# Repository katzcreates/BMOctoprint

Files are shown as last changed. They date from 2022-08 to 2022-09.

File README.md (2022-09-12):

# BMOctoprint: The DIY Octoprint Server Shaped like BMO from Adventure Time!

So you followed along with my [BMOctoprint](https://katzcreates.com/portfolio/bmoctoprint) project and want to try your hand at making your own? Well, congratulations! You're in the right place and you are in for a treat because BMOctoprint is the sweetest, cutest, loveliest Octoprint server there ever was. 

All of the files you need to recreate my version of BMOctoprint can be found here in this repository. However, if you wish to make alterations to make BMO your own, you are encouraged to do so! You can even create forks of this repository to add your own code or altered 3D printing files. I would love to see what other versions of BMO people can make with what I have started, so please share your results if you end out taking a different approach!

### The full, detailed build instructions can be found on [here on Instructables](https://www.instructables.com/Life-Sized-Talking-BMO-From-Adventure-Time-thats-A/).

## Getting Started

This is a rather involved build with a fair bit of expenditure involved with a handful of parts being needed! Below are the components/necessary materials that I used to create BMOctoprint and therefore will work perfectly with the case/code as provided. If you wish to use different components then feel free, but alterations may be necessary to make everything fit!

### Electronics (links are not affiliate links and UK specific)
- A Raspberry Pi 4 (I used a 8GB model which worked great and I recommend it. A smaller model may be fine as well or may run a bit slower.)
   - (If you are going to be running Octoprint then a Pi 4 is a requirement as older models struggle to run it and I have not tested this setup with a Pi Zero.)
- [7 inch Raspberry Pi Touchscreen](https://shop.pimoroni.com/products/raspberry-pi-7-touchscreen-display-with-frame?variant=2677960835082)
   - (This is super easy to use, fits the case perfectly and allows the Pi to mount right to the back of it. It is also quite expensive and there are probably cheaper options that can work with adjustments.)
- [Adafruit I2S Speaker Bonnet](https://shop.pimoroni.com/products/adafruit-i2s-3w-stereo-speaker-bonnet-for-raspberry-pi-mini-kit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)
- One (1) extra long 40 pin header
- Two (2) [3 inch Speakers](https://shop.pimoroni.com/products/3-speaker-4-3w?variant=380549926)
- Three (3) [12mm Tactile Switches](https://shop.pimoroni.com/products/tactile-switches?variant=372242669)
- Four (4) [6mm Tactile Switches](https://shop.pimoroni.com/products/tactile-switches?variant=372242667)
- One (1) USB-C Panel Mount (capable of power delivery, this is important!!)
- Four (4) [USB-A Panel Mounts (2 Left Angle and 2 Right Angle)](https://www.ebay.co.uk/itm/232860372185)
- Seven (7) 10K resistors
- A custom [BMOctoprint PCB](https://www.pcbway.com/project/shareproject/BMOctoprint_Buttons_PCB_2d7beb47.html) or other mounting for the tactile switches

### Additional Components/Materials
- One (1) KG of [Teal PETG filament](https://eu.polymaker.com/product/polylite-petg/?aff=44) (affiliate link)
   - (Total printed weight will depend on your print settings, but 1KG should see you through)
- 50g Black PETG filament
- Small amounts of Yellow, Red, Green and Blue PLA
- 3mm Flexible Armature Wire
- Eight (8) M4x6 screws (cap head preferred for all screws)
- Four (4) M3x4 screws
- Eight (8) M3x8 screws
- Eight (8) M3x16 screws
- Two (2) 8x3mm Neodymium Magnets (optional)

I highly recommend a keyboard you can connect to the Pi as well to make setting things up easier, however, it is not required. You can do everything on the touchscreen, but it may take a lot longer than with a keyboard!

You will also require some basic electronics kit and tools such as a soldering iron, solder, a breadboard, kapton tape and a range of wiring. A 3D printer is essential as well, of course!
<br/>

### Pi Software Setup

To run all of the current code and software for BMOctoprint, you will need to use the **Buster OS** build of Raspbian. 
> The current build (Bullseye) will not work as OMXPlayer is not compatible with it. 

I recommend downloading and using the [Raspberry Pi Installer tool](https://www.raspberrypi.com/software/) to get this set up. 

#### Required Installs
- OMXPlayer ([Documentation](https://github.com/popcornmix/omxplayer))
- [OMXPlayer-Wrapper](https://pypi.org/project/omxplayer-wrapper/) ([Documentation](https://python-omxplayer-wrapper.readthedocs.io/en/latest/#))
- [Xscreensaver](https://www.jwz.org/xscreensaver/) ([Documentation](https://linux.die.net/man/1/xscreensaver-command))
- [Feh](https://feh.finalrewind.org/) ([Documentation](https://man.finalrewind.org/1/feh/))
- [Octoprint](https://octoprint.org/) (NOT Octopi!) ([Install Instructions](https://community.octoprint.org/t/setting-up-octoprint-on-a-raspberry-pi-running-raspberry-pi-os-debian/2337))

### Additional relevant instructions can be found inside the individual folders, and full detailed build instructions are on [here on Instructables](https://www.instructables.com/Life-Sized-Talking-BMO-From-Adventure-Time-thats-A/). If I missed anything or you get stuck, please open an issue or send a message and I'll be happy to try and help!
<br/>
<br/>
<br/>
<br/>

Shield: [][cc-by-nc-sa]

This work is licensed under a
[Creative Commons Attribution-NonCommercial-ShareAlike 4.0 International License][cc-by-nc-sa].

[][cc-by-nc-sa]

[cc-by-nc-sa]: http://creativecommons.org/licenses/by-nc-sa/4.0/
[cc-by-nc-sa-image]: https://licensebuttons.net/l/by-nc-sa/4.0/88x31.png
[cc-by-nc-sa-shield]: https://img.shields.io/badge/License-CC%20BY--NC--SA%204.0-lightgrey.svg

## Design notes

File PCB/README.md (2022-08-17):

PCB Gerber files can be found here! If you wish to manufacture the PCB yourself, please help yourself to the following files. 

I'd love to see other versions of this, so please share the results here or on social media if possible!

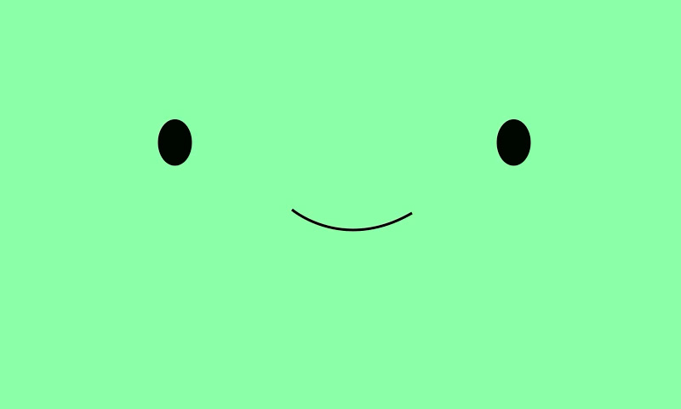
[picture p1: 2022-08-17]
Animation Files/BMO_Idle.jpg

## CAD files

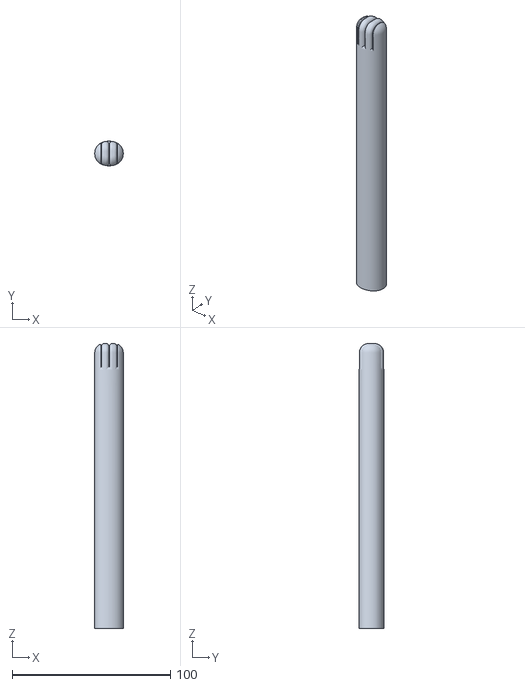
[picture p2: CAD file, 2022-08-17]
Print Files/BMOctoprint_Arm_Whole.stl
18.0 x 15.6 x 180.0

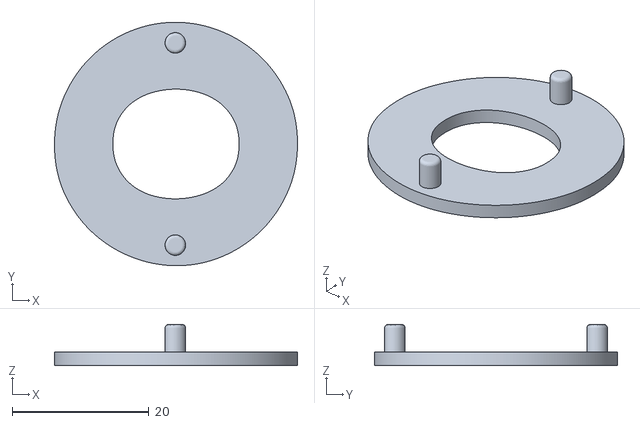
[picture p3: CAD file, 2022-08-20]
Print Files/BMOctoprint_O_Left.stl
35.5 x 35.5 x 6.00

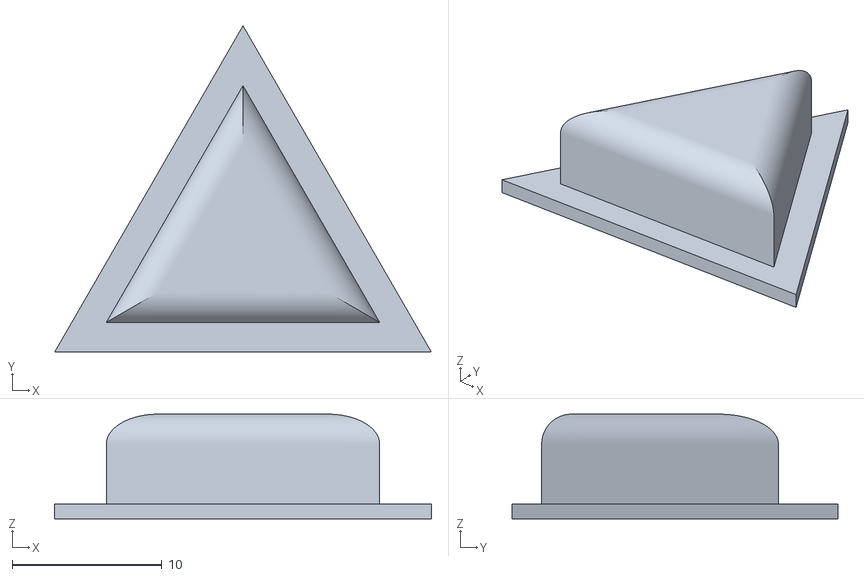
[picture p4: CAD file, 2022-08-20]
Print Files/BMOctoprint_BlueTriangleButton.stl
25.2 x 21.8 x 7.00

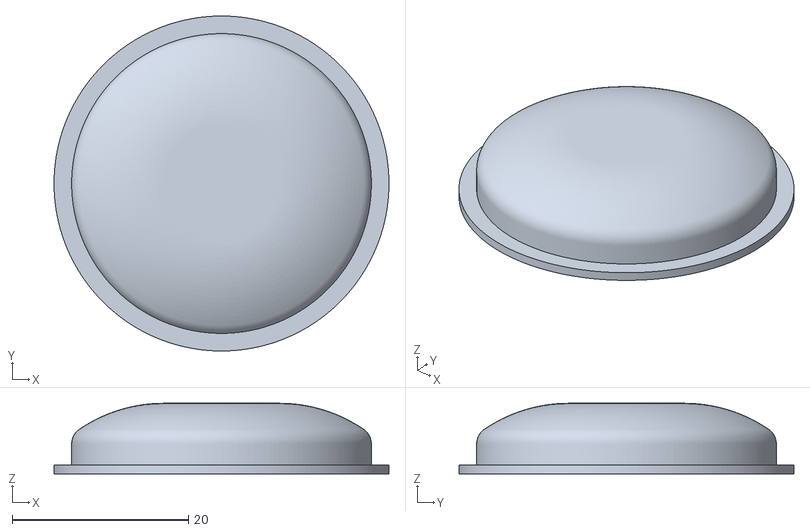
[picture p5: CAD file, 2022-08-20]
Print Files/BMOctoprint_BigRedButton.stl
38.0 x 38.0 x 8.00

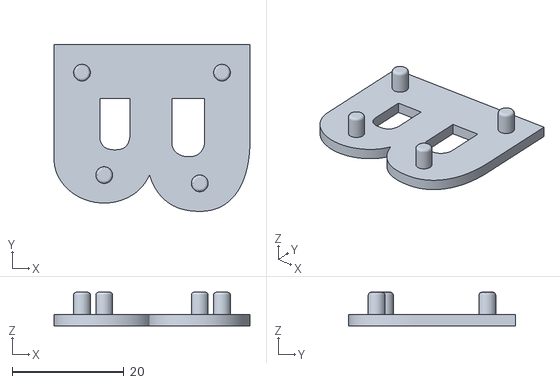
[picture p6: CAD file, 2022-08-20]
Print Files/BMOctoprint_B_Left.stl
35.0 x 29.8 x 6.00

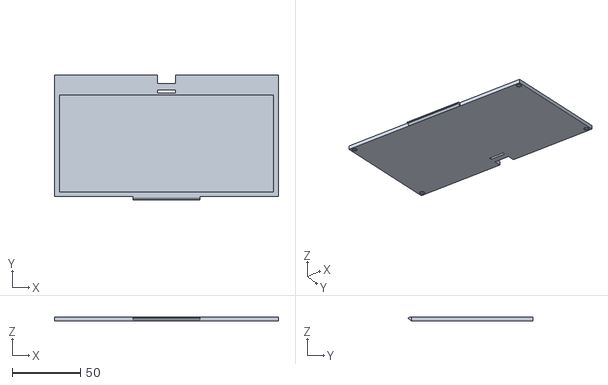
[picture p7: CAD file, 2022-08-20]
Print Files/BMOctoprint_ButtFlap.stl
164.0 x 91.3 x 3.00

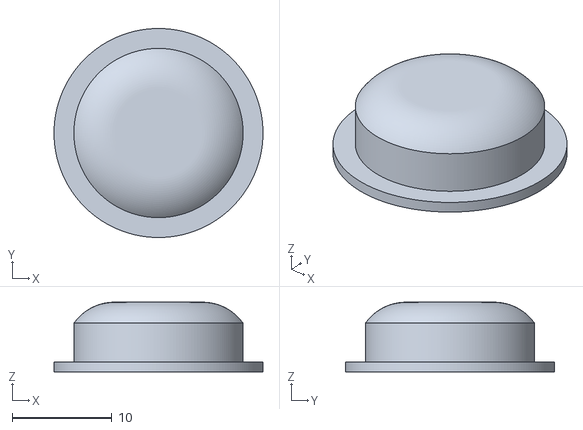
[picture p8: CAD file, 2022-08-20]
Print Files/BMOctoprint_SmallGreenButton.stl
21.0 x 21.0 x 7.00

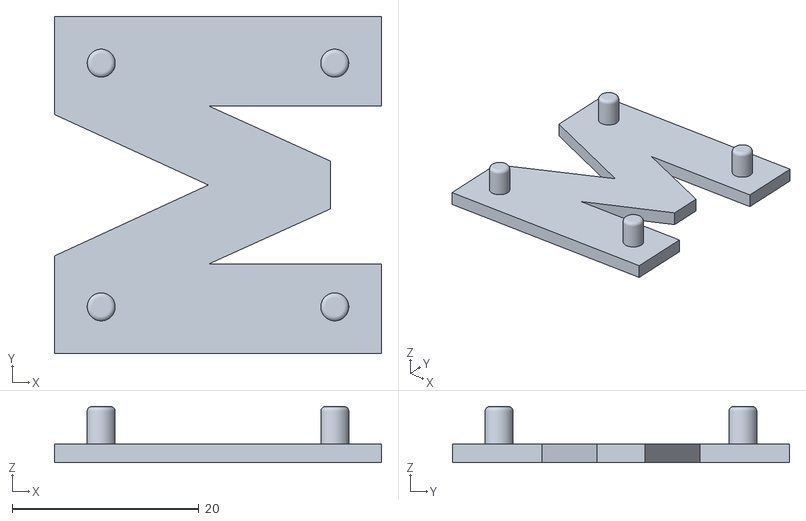
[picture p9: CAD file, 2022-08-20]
Print Files/BMOctoprint_M_Left.stl
35.0 x 36.1 x 6.00

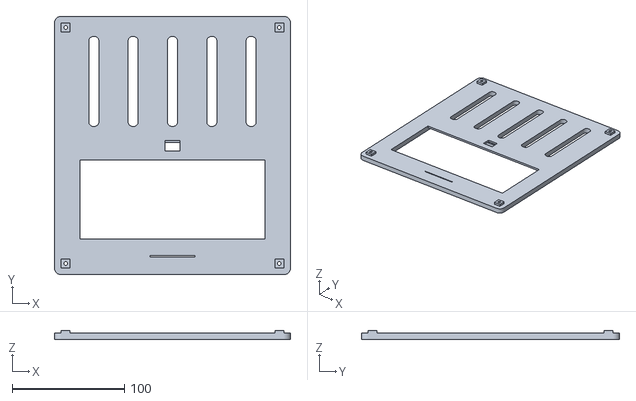
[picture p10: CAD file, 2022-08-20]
Print Files/BMOctoprint_BackPlate.stl
210.0 x 230.0 x 8.20

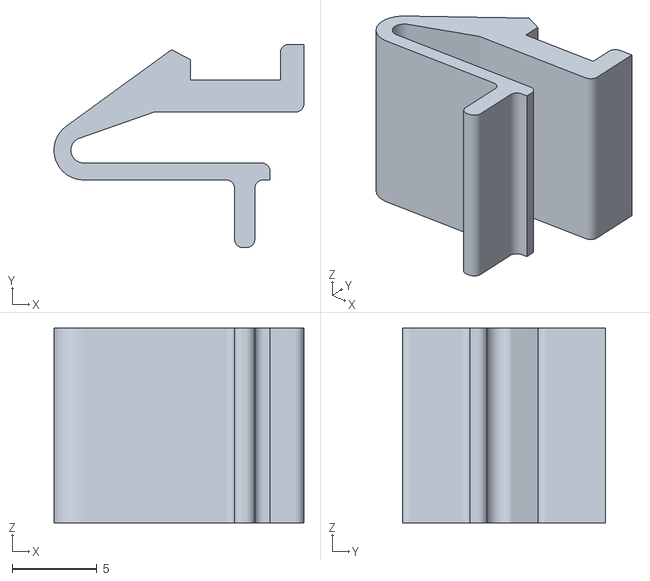
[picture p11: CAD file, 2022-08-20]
Print Files/BMOctoprint_ButtLatch.stl
14.7 x 12.0 x 11.5

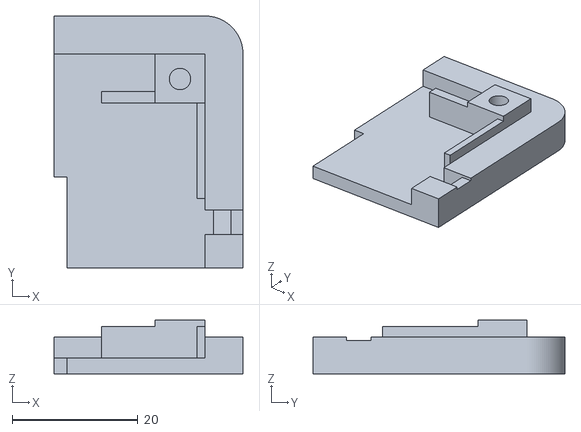
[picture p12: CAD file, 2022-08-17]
Print Files/TestFit_Front.stl
30.0 x 40.0 x 8.50

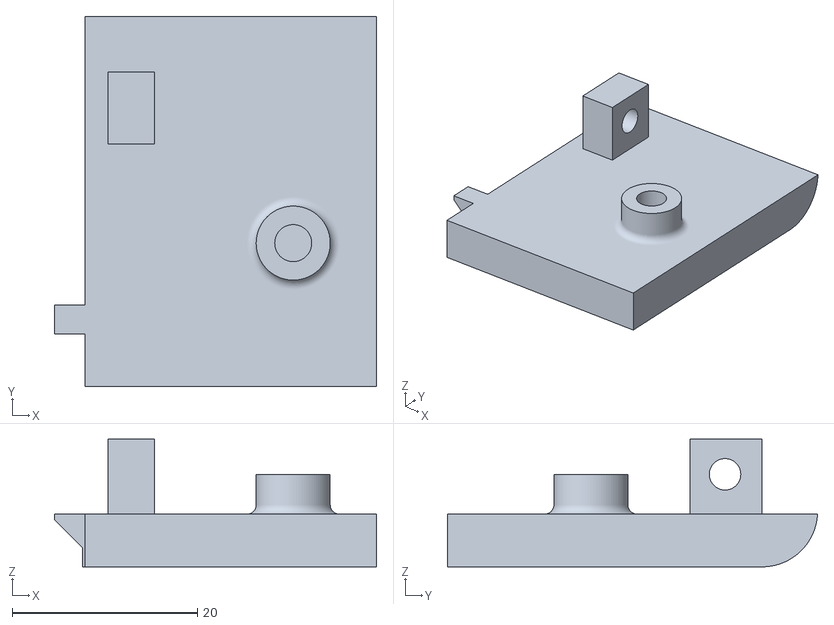
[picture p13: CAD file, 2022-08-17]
Print Files/TestFit_Right.stl
34.8 x 40.0 x 13.8

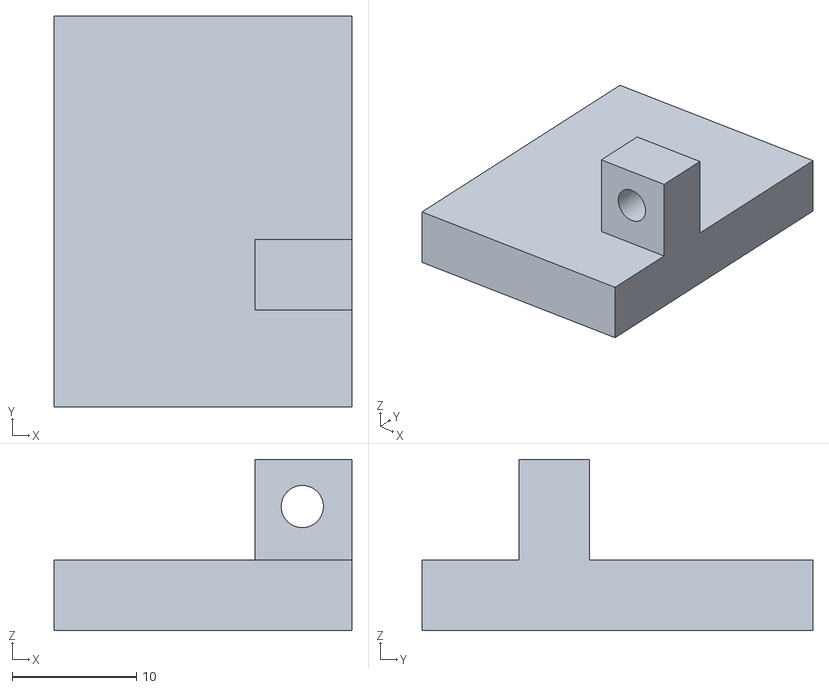
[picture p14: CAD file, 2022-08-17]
Print Files/TestFit_Top.stl
24.0 x 31.5 x 13.8

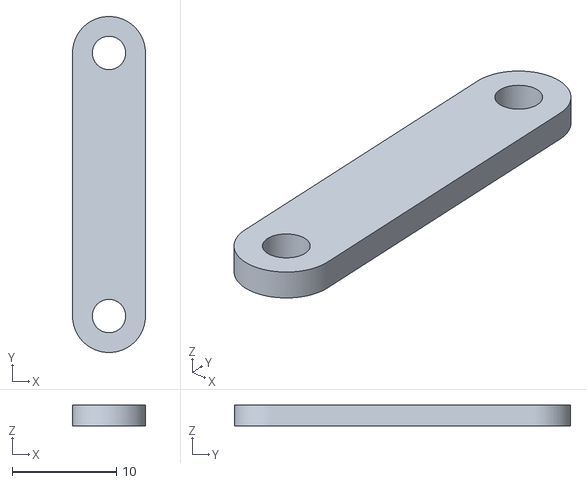
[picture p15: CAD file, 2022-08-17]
Print Files/BMOctoprint_DisplayMount01.stl
7.00 x 32.2 x 2.00

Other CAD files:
Print Files/BMOctoprint_DisplayMount02.stl
Print Files/BMOctoprint_LegPlug.stl
Print Files/BMOctoprint_FacePlate.stl
Print Files/BMOctoprint_LeftPlate.stl
Print Files/BMOctoprint.f3d
Print Files/BMOctoprint_ArmPlug.stl
Print Files/BMOctoprint_Arm_Segmented.stl
Print Files/BMOctoprint_B_Right.stl
Print Files/BMOctoprint_BottomPlate.stl
Print Files/BMOctoprint_DPad.stl
Print Files/BMOctoprint_DPad_ButtonPushPad.stl
Print Files/BMOctoprint_DPad_CenterPin.stl
Print Files/BMOctoprint_Faceplate_MiddleHoleCover.stl
Print Files/BMOctoprint_Faceplate_RoundHoleCover.stl
Print Files/BMOctoprint_Faceplate_SmallHoleCover.stl
Print Files/BMOctoprint_Hand_Segmented.stl
Print Files/BMOctoprint_LeftLeg.stl
Print Files/BMOctoprint_LegJoint.stl
Print Files/BMOctoprint_M_Right.stl
Print Files/BMOctoprint_O_Right.stl
Print Files/BMOctoprint_RightPlate.stl
Print Files/BMOctoprint_TopPlate.stl

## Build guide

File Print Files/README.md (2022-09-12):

# BMOctoprint 3D Printing Instructions

BMOctoprint's 3D printing files have been optimised to make printing as simple and straight forward as possible, **however**, as with all large 3D printing projects there is still a certain degree of prior 3D printing knowledge required to successfully create your build. 

## These are large prints! Please proceed with appropriate caution or risk wasting filament!

This folder contains all the individual pieces as **STL files**, as well as **CAD files** (.f3d and .STEP) that contain the whole model in 'assembled' form. The large case parts have been optimised for use with either a 0.4mm or 0.6mm nozzle, while the smaller pieces print best with either 0.4mm or smaller nozzles (I have successfully printed the buttons with a 0.1mm nozzle, but that is hardly necessary!). 

### I highly recommend printing the large case pieces with a 0.6mm nozzle to save on print time. While a 0.4mm nozzle can be used, it will take substantially more time and will not save on filament.

Tolerances should be fine for most printers, but it is still recommended that you print the provided **TestFit** pieces to check the fit of the pieces before committing to the larger prints. This will allow you to check the piece alignment/fit, as well as the fit for the screws. A M4x6 can be used to check the larger screw hole, and a M3x16 for the three aligned holes.

### **If you are struggling with tolerances and fit, it is possible to adjust these within the CAD files, but I'm afraid I cannot provide a range of part sizes for this due to the work involved. I am happy to advise on how to improve the fit but cannot provide additional files.** 

All STL files are in the best orientation for printing as is and don't require moving. Most pieces can be printed without supports, but minimal supports are required for some pieces. If unsure, print with supports!

Main case pieces and mounting pieces should be printed in PETG to handle the heat from the electronics without issue. I can highly recommend [Polymaker PolyLite PETG](https://eu.polymaker.com/product/polylite-petg/?aff=44) (affiliate link) in Teal for this, as it is the perfect BMO colour! 

BMO's limbs ideally should be printed in a soft TPU to allow for flexibility and posing! I used [Recreus Filaflex 82A in Blue](https://recreus.com/gb/filaments/9-694-filaflex-82a.html#/2-diameter-175_mm/3-weight-500_gr/14-colour-blue) with great results, [Polymaker PolyFlex 90A](https://eu.polymaker.com/product/polyflex-tpu90/?aff=44) (affiliate link) works as well if you struggle with softer TPU. The Arm model comes in two variations; a whole version and a segmented version. If you are struggling to print the whole version in one go but don't want to use the segmented version (less clean looking) it's also possible to 'slice' it into two pieces in your slicer of choice and use [TPU welding to put the two pieces together](https://www.instagram.com/reel/CcI-6JzDguU/?utm_source=ig_web_copy_link). **There are slots in the hands for neodymium magnets that can be pushed into place while the print is paused if you so desire.**

Buttons and other detail pieces can be printed in PLA or whatever you please! 

Some minor clean up may be required to get everything looking good and fitting together properly, but it should be minimal! If at all possible, print on a smooth or shiny print bed to get a BMO with a shiny surface! 

### Full build instructions can be found [here](https://www.instructables.com/Life-Sized-Talking-BMO-From-Adventure-Time-thats-A/).

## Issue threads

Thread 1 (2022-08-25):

while loop in python script causing high CPU consumption?

MatthewJohn, 2022-08-25:
I've just seen your video and looked at your python script..
I'm not sure if I'm missing something (in particular about how gpiozero.Button works)..
Looking at the documentation and how you're using gpiozero.Button, I think either of one these is true, which may cause unnecessary CPU usage:
 * Looping and checking each of the buttons - I imagine this is causing a high amount of CPU load? If octoprint is running in the background, maybe this could cause some print issues - perhaps a very small sleep at end of the for while loop would work (https://github.com/katzcreates/BMOctoprint/blob/main/Code%20Files/BMOFaceButtons.py#L68)?
```
    from time import sleep
    while True:
        button_right.when_pressed = video_right
        button_up.when_pressed = video_up
        button_down.when_pressed = video_down
        button_left.when_pressed = video_left
        sleep(0.1)

    pause()
```
 * Alternatively (and if true, a more beneficial change), having had a brief look at the docs/example for gpiozero.Button:
```
    from gpiozero import LED, Button:
    from signal import pause

    led = LED(17)
    button = Button(3)

    button.when_pressed = led.on
    button.when_released = led.off

    pause()
```
   the example appears to suggest that button.when_pressed is just setting up a callback for when the button is pressed. Therefore, once entering the thread `pause()`, the callback will happen, meaning the `while` loop is not necessary at all re-setting up the callback over and over, wasting CPU time. So it could look like:
```
    button_right.when_pressed = video_right
    button_up.when_pressed = video_up
    button_down.when_pressed = video_down
    button_left.when_pressed = video_left

    pause()
```

Apologies if I've missed something (either obvious or not) and I have absolutely no means of testing any of this (PI, 3d printer or BMO) :D

katzcreates, 2022-09-08:
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

Hey! Thank you so much for noting this. You are absolutely right; the `while` loop is not necessary and I had just missed that in the documentation. I've tested your theory and it is working perfectly! I shall update the code here so everyone can benefit from your insight. 😀 Thank you so much!

MatthewJohn, 2022-12-11:
For reference: aa8eac3b318e5cdad17138410bee72f418423924

Closed 2022-09-08.

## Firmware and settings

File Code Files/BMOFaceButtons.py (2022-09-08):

from gpiozero import Button #Much easier way to interact with the GPIO
from omxplayer import OMXPlayer
from pathlib import Path
import time
from signal import pause
import os
import subprocess

button_right = Button(6) 
button_up = Button(16)
button_left = Button (5)
button_down = Button (25)

def video_right():
    image = subprocess.Popen(["feh", "--hide-pointer", "-x", "-F", "/home/pi/BMO/BMO_Idle.jpg"])
    time.sleep(0.1)
    os.system("xscreensaver-command -deactivate")
    time.sleep(0.1)
    VIDEO_PATH = Path("/home/pi/BMO/BMO_DontSayThings_ColorAdjust.mp4")
    player = OMXPlayer(VIDEO_PATH, args=['-o', 'alsa'])
    player.set_aspect_mode('stretch')
    player.set_rate(0.975)
    time.sleep(4.7)
    os.system("xscreensaver-command -activate")
    image.kill()
    
    
def video_up():
    image = subprocess.Popen(["feh", "--hide-pointer", "-x", "-F", "/home/pi/BMO/BMO_Idle.jpg"])
    time.sleep(0.1)
    os.system("xscreensaver-command -deactivate")
    time.sleep(0.1)
    VIDEO_PATH = Path("/home/pi/BMO/BMO_WorryBaby_ColorAdjust.mp4")
    player = OMXPlayer(VIDEO_PATH, args=['-o', 'alsa'])
    player.set_aspect_mode('stretch')
    player.set_rate(0.975)
    time.sleep(3.5)
    os.system("xscreensaver-command -activate")
    image.kill()
    
def video_down():
    image = subprocess.Popen(["feh", "--hide-pointer", "-x", "-F", "/home/pi/BMO/BMO_Idle.jpg"])
    time.sleep(0.1)
    os.system("xscreensaver-command -deactivate")
    time.sleep(0.1)
    VIDEO_PATH = Path("/home/pi/BMO/BMO_YourHand_ColorAdjust.mp4")
    player = OMXPlayer(VIDEO_PATH, args=['-o', 'alsa'])
    player.set_aspect_mode('stretch')
    player.set_rate(0.975)
    time.sleep(4)
    os.system("xscreensaver-command -activate")
    image.kill()
    
def video_left():
    image = subprocess.Popen(["feh", "--hide-pointer", "-x", "-F", "/home/pi/BMO/BMO_Idle.jpg"])
    time.sleep(0.1)
    os.system("xscreensaver-command -deactivate")
    time.sleep(0.1)
    VIDEO_PATH = Path("/home/pi/BMO/BMO_WelcomeFriends_ColorAdjust.mp4")
    player = OMXPlayer(VIDEO_PATH, args=['-o', 'alsa'])
    player.set_aspect_mode('stretch')
    player.set_rate(0.975)
    time.sleep(6)
    os.system("xscreensaver-command -activate")
    image.kill()
    
    
button_right.when_pressed = video_right
button_up.when_pressed = video_up
button_down.when_pressed = video_down
button_left.when_pressed = video_left

pause()

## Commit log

2022-08-20 File Orientation Fix
    [BMOctoprint_B_Left.stl, BMOctoprint_BackPlate.stl, BMOctoprint_BigRedButton.stl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]
2022-09-08 Update BMOFaceButtons.py
    Removed `while` loop from button callback
2022-09-12 Updated printing instructions with full build link

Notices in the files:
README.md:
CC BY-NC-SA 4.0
